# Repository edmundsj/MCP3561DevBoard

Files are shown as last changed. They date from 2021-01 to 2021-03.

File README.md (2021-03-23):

# MCP3561 Development Board
Development board for MCP3561 ADC, a <153kSpS
sigma-delta (oversampling) ADC capable of ~108dB SNR.

## Features
- 3.3V on-board reference
- low-noise 3.3V digital and analog supplies
- Powered via single 4V-12V input voltage
- Sampling rate tested up to 10kHz
- BNC input synchronization
- Single-channel SMA analog input
- Based on the Teensy 4.1, micro-USB communication to PC
- Additional digital/analog outputs (used here for motor control)

Populated PCB
Unpopulated PCB

## Performance Data
Measured with MCLK=10MHz, OSR=256, fs=9.76kHz, Av=1
- Rms voltage noise 9.8uV, PSD=143nV/rtHz, 0.2kHz to fs/2

Measured with MCLK=10MHz, OSR=256, fs=9.76kHz, Av=10
- Rms voltage noise is 13.4uV, PSD=195nV/rtHz, 0.2kHz to fs/2

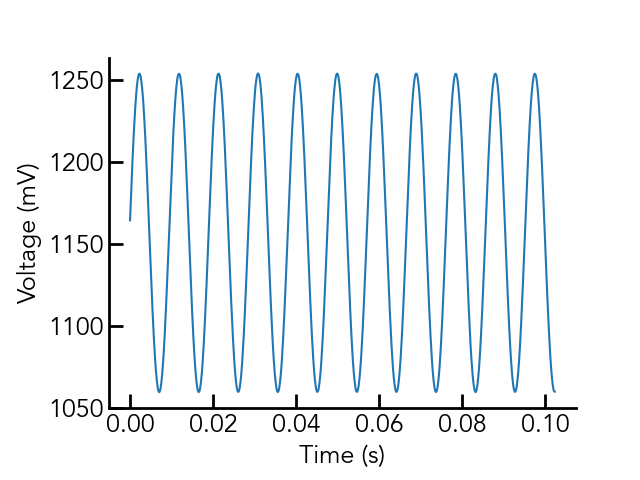
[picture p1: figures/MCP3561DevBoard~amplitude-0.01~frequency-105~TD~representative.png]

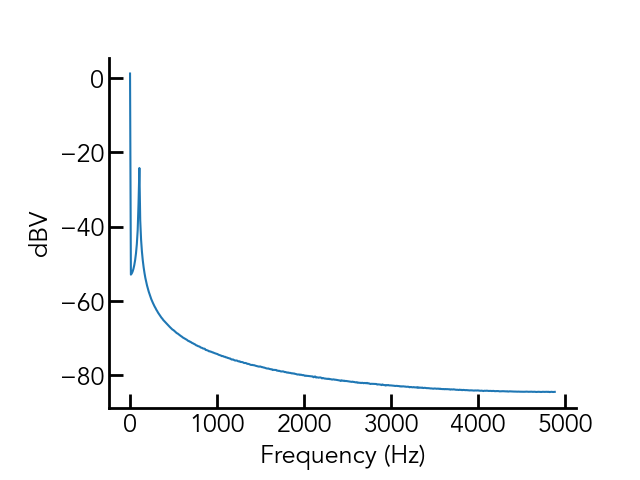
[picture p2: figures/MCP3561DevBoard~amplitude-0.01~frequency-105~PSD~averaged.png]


Fig. 3 and 4 show the same plots with an input signal of 10mVrms (Av=10) at
105Hz.

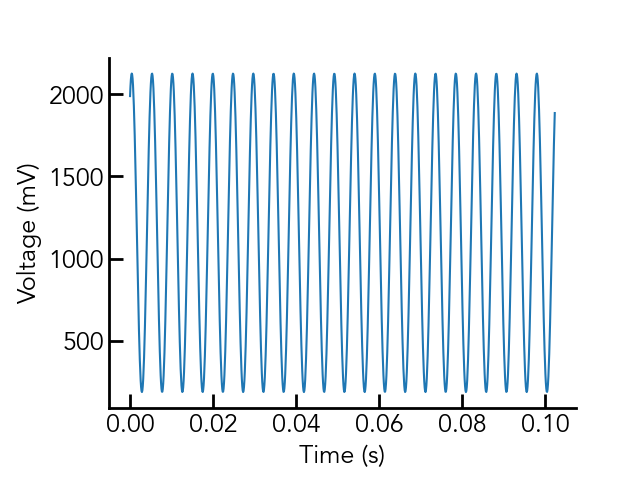
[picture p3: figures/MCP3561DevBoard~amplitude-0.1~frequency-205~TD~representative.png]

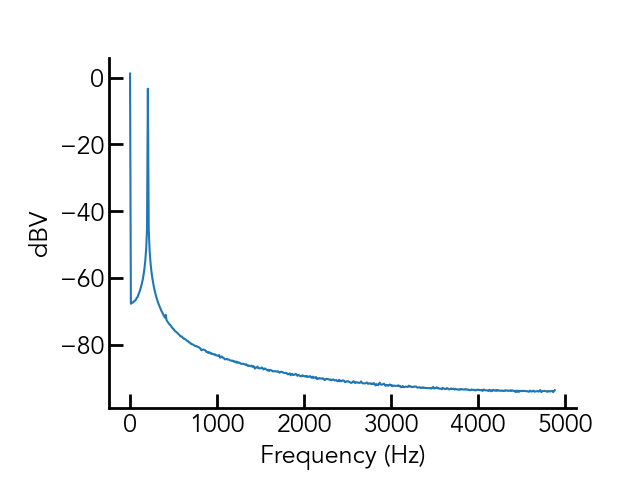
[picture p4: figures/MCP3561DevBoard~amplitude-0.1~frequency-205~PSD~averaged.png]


Fig. 5 and 6 show the same plots with an input signal of 100mVrms (Av=10) at
205Hz. 

## Getting Started
Using this dev board requires you have python installed on your computer, as
well as the Teensyduino IDE. You must then upload the code in ``arduino_code/``
to the Teensy being used for measurement, which I have written to communicate
via the arduino ``Serial()`` interface (USB) using the SCPI language. Feel free
to communicate with it using your own scripts, but I have written a python
implementation which can be found in ``MCP3561.py``
[here](https://github.com/edmundsj/AD7766_Python.git).

## Issues
### Issues in version 1
- [FIXED v2] U3 (TLV opamp) package is incorrect - TSOT353, actual package is SOT23-5.
- 1/f noise of TLV opamp is appreciable when configured for a gain of 10.

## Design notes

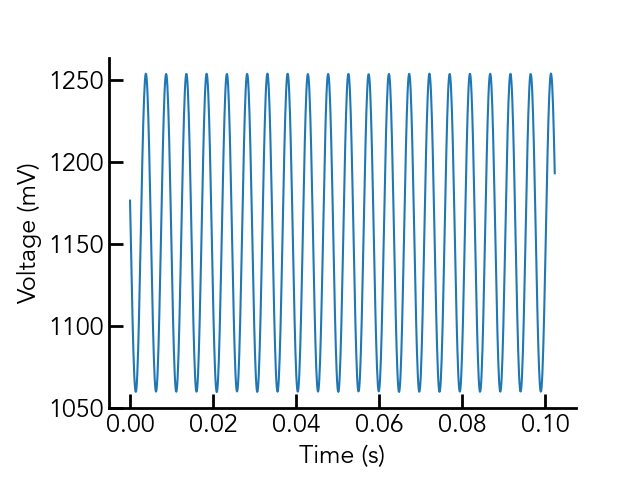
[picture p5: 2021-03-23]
figures/MCP3561DevBoard~amplitude-0.01~frequency-205~TD~representative.png

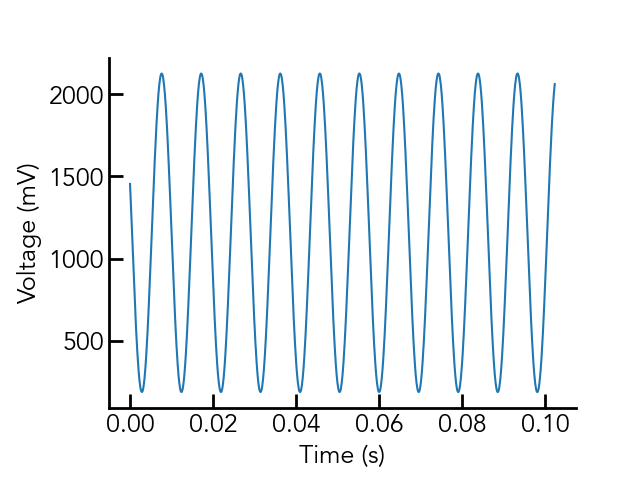
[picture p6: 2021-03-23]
figures/MCP3561DevBoard~amplitude-0.1~frequency-105~TD~representative.png

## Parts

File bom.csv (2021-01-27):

Part Name |  | Source | Catalog Number | Link | Quantity
U8 | Teensy4.1 | Digikey |  |  | 1
U7 | MCP3561 | Digikey | MCP3561RT-E/ST | https://www.digikey.com/en/products/detail/microchip-technology/MCP3561RT-E-ST/12807296 | 1
> U5, U6 | ADP3330-3.3 | Digikey | ADP3330ARTZ3.3-RL7CT-ND | https://www.digikey.com/en/products/detail/analog-devices-inc/ADP3330ARTZ3-3-RL7/1007321 | 2
U4 | ADR366 | Digikey | ADR366AUJZ-REEL7 | https://www.digikey.com/en/products/detail/analog-devices-inc/ADR366AUJZ-REEL7/996001 | 1
U3 | TLV9051 | Digikey | TLV9051IDBVR | https://www.digikey.com/en/products/detail/texas-instruments/TLV9051IDBVR/10715425 | 1
FL1-3 | LCL Filter | Digikey | 490-6957-1-ND | https://www.digikey.com/en/products/detail/murata-electronics/NFL21SP157X1C3D/2595155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 | 3
> R8-R12 | 10R | Digikey |  |  | 4
> R3, R6 | 1k | Digikey |  |  | 2
R7 | 100R | Digikey |  |  | 1
R5 | 3k | Digikey |  |  | 1
> R1, R4 | 10k | Digikey |  |  | 2
R2 | 320R | Digikey |  |  | 1
J8 | Screw_Terminal_01x02 | Digikey |  |  | 1
J5 | Conn_01x04 | Digikey |  |  | 1
J7 | Conn_01x10_Male | Digikey |  |  | 1
> J3, J4, J6 | Conn_02x03_Counter_Clockwise | Digikey |  |  | 3
J1 | Conn_Coaxial | Digikey |  |  | 1
J2 | Conn_Coaxial | Digikey |  |  | 1
> H1-H4 | MountingHole | Digikey |  |  | 4
> FL1, FL2 | EMI_Filter_LCL | Digikey |  |  | 2
D1 | DIODE | Digikey |  |  | 1
C7 | 100nF | Digikey |  |  | 1
> C1-C6, C8-C10 | 470nF | Digikey |  |  | 9

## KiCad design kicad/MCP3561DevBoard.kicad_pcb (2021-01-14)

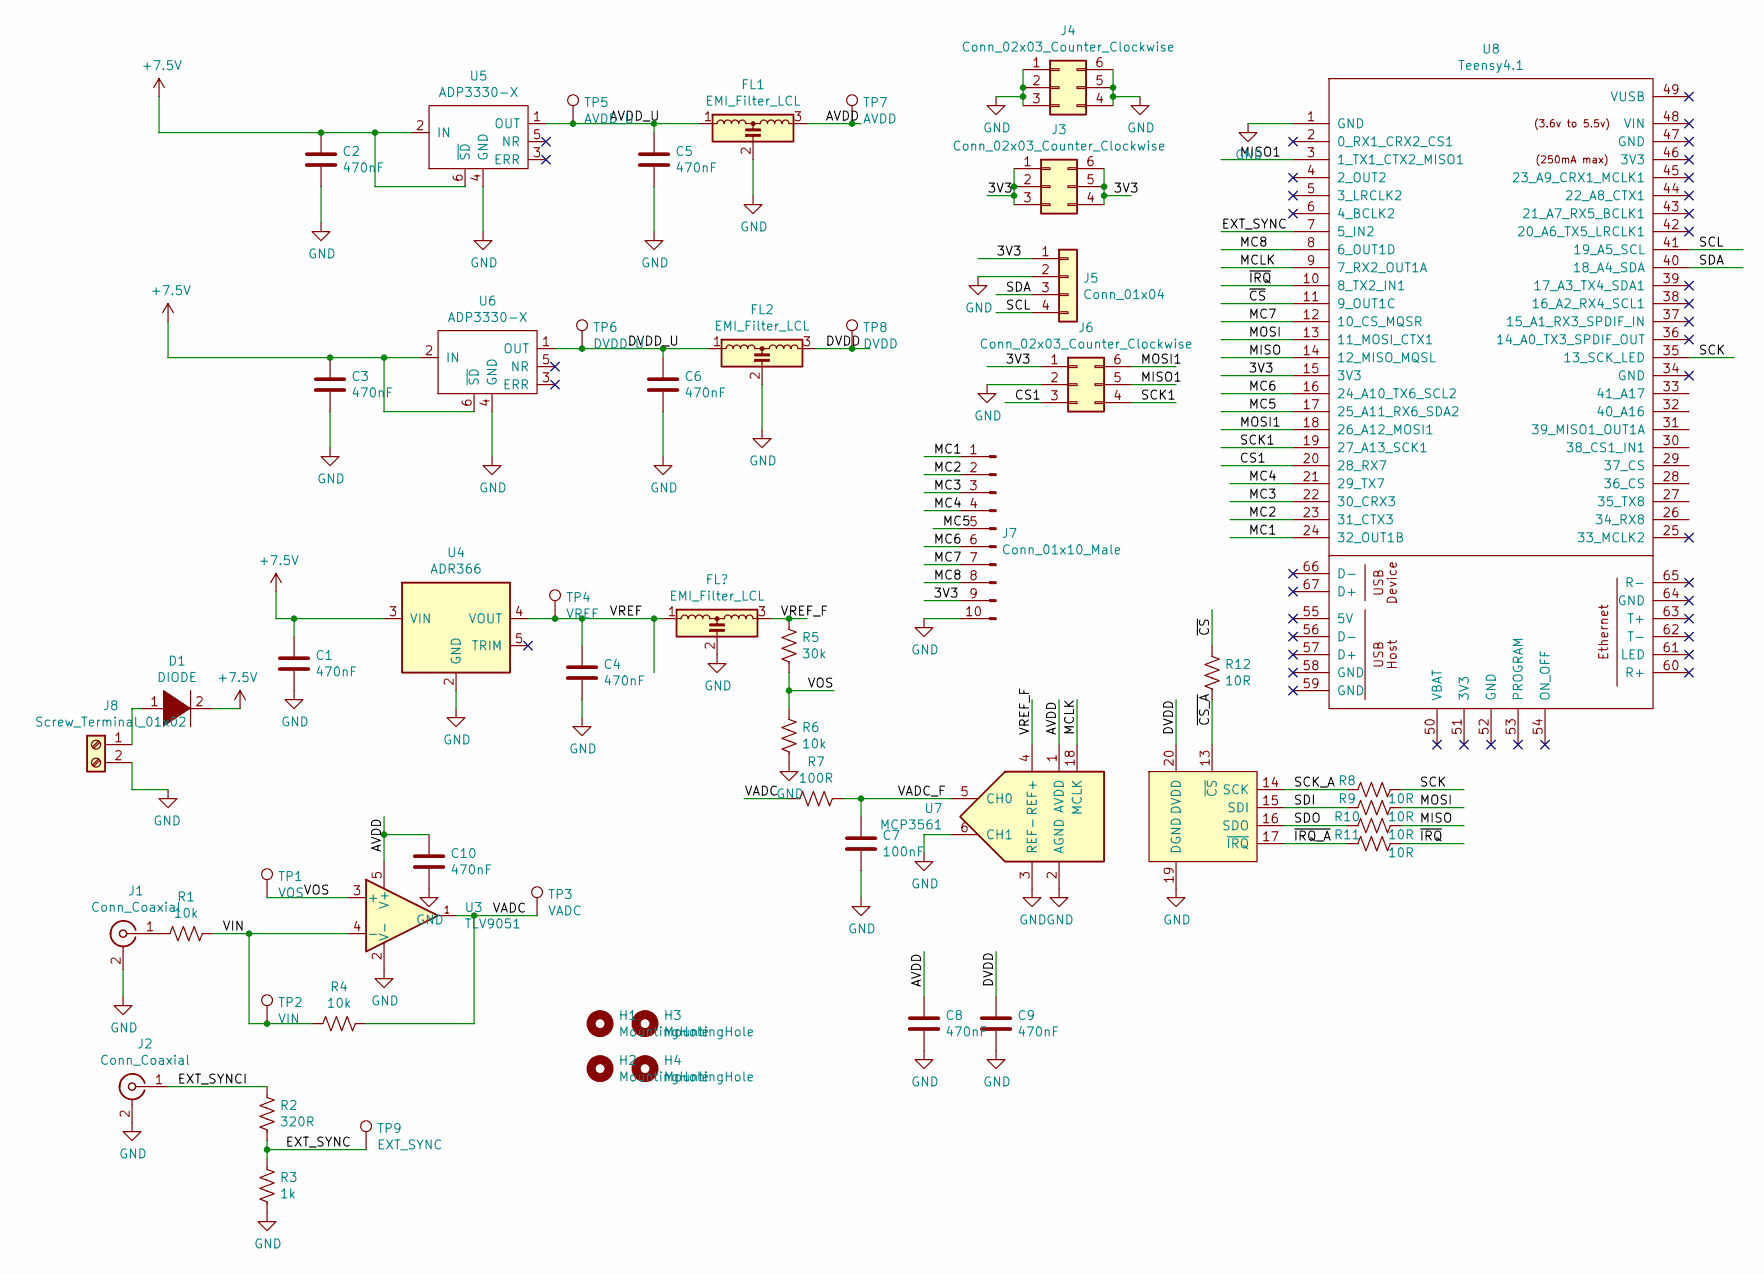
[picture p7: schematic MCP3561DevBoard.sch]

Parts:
C1, C2, C3, C4, C5, C6, C8, C9, C10: 470nF; C_0805_2012Metric_Pad1.15x1.40mm_HandSolder
C7: 100nF; C_0805_2012Metric_Pad1.15x1.40mm_HandSolder
D1: DIODE; D_SMA-SMB_Universal_Handsoldering
FL1, FL2: EMI_Filter_LCL; 0805_3TERM
H1, H2, H3, H4: MountingHole; m3_mounting_hole
J1: Conn_Coaxial; CON-SMA-EDGE-S
J2: Conn_Coaxial; BNC_JACK_RA
J3, J4, J6: Conn_02x03_Counter_Clockwise; PinHeader_2x03_P2.54mm_Vertical
J5: Conn_01x04; PinHeader_1x04_P2.54mm_Vertical
J7: Conn_01x10_Male; PinHeader_1x10_P2.54mm_Vertical
J8: Screw_Terminal_01x02; TerminalBlock_Altech_AK300-2_P5.00mm
R1, R4, R6: 10k; R_0805_2012Metric_Pad1.15x1.40mm_HandSolder
R2: 320R; R_0805_2012Metric_Pad1.15x1.40mm_HandSolder
R3: 1k; R_0805_2012Metric_Pad1.15x1.40mm_HandSolder
R5: 30k; R_0805_2012Metric_Pad1.15x1.40mm_HandSolder
R7: 100R; R_0805_2012Metric_Pad1.15x1.40mm_HandSolder
R8, R9, R10, R11, R12: 10R; R_0805_2012Metric_Pad1.15x1.40mm_HandSolder
TP1: VOS; TestPoint_Keystone_5000-5004_Miniature
TP2: VIN; TestPoint_Keystone_5000-5004_Miniature
TP3: VADC; TestPoint_Keystone_5000-5004_Miniature
TP4: VREF; TestPoint_Keystone_5000-5004_Miniature
TP5: AVDD_U; TestPoint_Keystone_5000-5004_Miniature
TP6: DVDD_U; TestPoint_Keystone_5000-5004_Miniature
TP7: AVDD; TestPoint_Keystone_5000-5004_Miniature
TP8: DVDD; TestPoint_Keystone_5000-5004_Miniature
TP9: EXT_SYNC; TestPoint_Keystone_5000-5004_Miniature
U3: TLV9051; SOT-23-5_HandSoldering
U4: ADR366; TSOT-23-5_HandSoldering
U5, U6: ADP3330-X; SOT-23-6_Handsoldering
U7: MCP3561; TSSOP-20_4.4x6.5mm_P0.65mm
U8: Teensy4.1; Teensy41

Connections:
+7.5V: C1.1, C2.1, C3.1, D1.2 (A), U4.3 (VIN), U5.2 (IN), U5.6 (~SD), U6.2 (IN), U6.6 (~SD)
/3V3: J3.1, J3.2, J3.3, J3.4, J3.5, J3.6, J5.1, J6.1, J7.9, U8.15 (3V3)
/AVDD: C8.1, C10.1, FL1.3, TP7.1, U3.5 (V+), U7.1 (AVDD)
/AVDD_U: C5.1, FL1.1, TP5.1, U5.1 (OUT)
/CS1: J6.3, U8.20 (28_RX7)
/DVDD: C9.1, FL2.3, TP8.1, U7.20 (DVDD)
/DVDD_U: C6.1, FL2.1, TP6.1, U6.1 (OUT)
/EXT_SYNC: R2.2, R3.1, TP9.1, U8.7 (5_IN2)
/EXT_SYNCI: J2.1 (In), R2.1
/MC1: J7.1, U8.24 (32_OUT1B)
/MC2: J7.2, U8.23 (31_CTX3)
/MC3: J7.3, U8.22 (30_CRX3)
/MC4: J7.4, U8.21 (29_TX7)
/MC5: J7.5, U8.17 (25_A11_RX6_SDA2)
/MC6: J7.6, U8.16 (24_A10_TX6_SCL2)
/MC7: J7.7, U8.12 (10_CS_MQSR)
/MC8: J7.8, U8.8 (6_OUT1D)
/MCLK: U7.18 (MCLK), U8.9 (7_RX2_OUT1A)
/MISO: R10.1, U8.14 (12_MISO_MQSL)
/MISO1: J6.5, U8.3 (1_TX1_CTX2_MISO1)
/MOSI: R9.1, U8.13 (11_MOSI_CTX1)
/MOSI1: J6.6, U8.18 (26_A12_MOSI1)
/SCK: R8.1, U8.35 (13_SCK_LED)
/SCK1: J6.4, U8.19 (27_A13_SCK1)
/SCK_A: R8.2, U7.14 (SCK)
/SCL: J5.4, U8.41 (19_A5_SCL)
/SDA: J5.3, U8.40 (18_A4_SDA)
/SDI: R9.2, U7.15 (SDI)
/SDO: R10.2, U7.16 (SDO)
/VADC: R4.1, R7.2, TP3.1, U3.1 (OUT)
/VADC_F: C7.1, R7.1, U7.5 (CH0)
/VIN: R1.1, R4.2, TP2.1, U3.4 (-)
/VOS: R5.2, R6.1, TP1.1, U3.3 (+)
/~CS: R12.1, U8.11 (9_OUT1C)
/~CS_A: R12.2, U7.13 (~CS)
/~IRQ: R11.1, U8.10 (8_TX2_IN1)
/~IRQ_A: R11.2, U7.17 (~IRQ)
GND: C1.2, C2.2, C3.2, C4.2, C5.2, C6.2, C7.2, C8.2, C9.2, C10.2, FL1.2, FL2.2, J1.2 (Ext), J2.2 (Ext), J4.1, J4.2, J4.3, J4.4, J4.5, J4.6, J5.2, J6.2, J7.10, J8.2, R3.2, R6.2, U3.2 (V-), U4.2 (GND), U5.4 (GND), U6.4 (GND), U7.2 (AGND), U7.3 (REF-), U7.6 (CH1), U7.19 (DGND), U8.1 (GND)
unnamed: D1.1 (K), J8.1
unnamed: J1.1 (In), R1.2

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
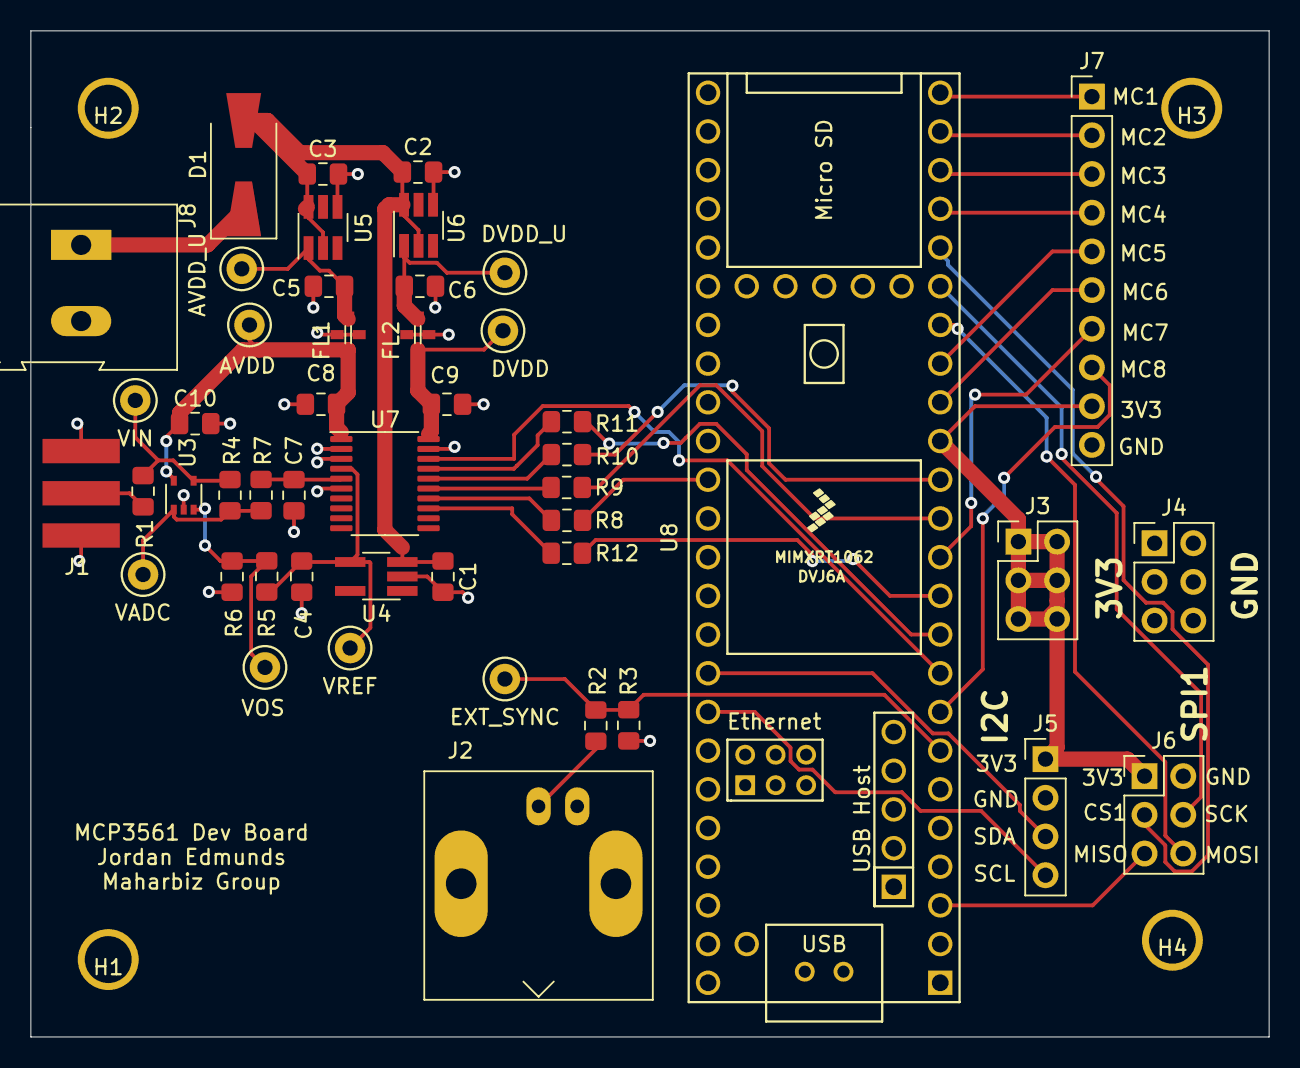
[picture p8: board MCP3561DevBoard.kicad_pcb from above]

Board: 2 copper layers, 81.3 x 66.0 mm, 52 parts (0 on the bottom side), 41 nets.

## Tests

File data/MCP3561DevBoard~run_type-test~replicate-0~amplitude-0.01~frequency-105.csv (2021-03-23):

{'sampling_frequency': 9760 | 'n_samples': 1000}
Time (s) | Voltage (mV) | Sync
0.0 | 1107.8404068946838 | 0
0.00010245901639344262 | 1113.5225415229797 | 0
0.00020491803278688525 | 1119.4418907165527 | 0
0.00030737704918032784 | 1125.5854725837705 | 0
0.0004098360655737705 | 1131.8742156028748 | 0
0.0005122950819672131 | 1138.2235407829285 | 0
0.0006147540983606557 | 1144.8533535003662 | 0
0.0007172131147540983 | 1151.3808846473694 | 0
0.000819672131147541 | 1157.996141910553 | 0
0.0009221311475409836 | 1164.589762687683 | 0
0.0010245901639344263 | 1171.0386157035828 | 0
0.001127049180327869 | 1177.5035977363586 | 0
0.0012295081967213114 | 1183.8411211967468 | 0
0.001331967213114754 | 1190.020501613617 | 0
0.0014344262295081967 | 1196.0854053497314 | 0
0.0015368852459016393 | 1201.9579410552979 | 0
0.001639344262295082 | 1207.6743006706236 | 0
0.0017418032786885246 | 1213.28444480896 | 0
0.0018442622950819673 | 1218.5771226882932 | 0
0.00194672131147541 | 1223.3670473098755 | 0
0.0020491803278688526 | 1227.956736087799 | 0
0.002151639344262295 | 1232.254135608673 | 0
0.002254098360655738 | 1236.1907958984375 | 0
0.0023565573770491805 | 1239.8017287254333 | 0
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

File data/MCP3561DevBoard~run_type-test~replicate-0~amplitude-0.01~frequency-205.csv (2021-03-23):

{'sampling_frequency': 9760 | 'n_samples': 1000}
Time (s) | Voltage (mV) | Sync
0.0 | 1123.9529013633726 | 0
0.00010245901639344262 | 1112.1901273727417 | 0
0.00020491803278688525 | 1101.2188553810117 | 0
0.00030737704918032784 | 1091.4021849632263 | 0
0.0004098360655737705 | 1082.601249217987 | 0
0.0005122950819672131 | 1074.899446964264 | 0
0.0006147540983606557 | 1068.736982345581 | 0
0.0007172131147540983 | 1064.1307711601257 | 0
0.000819672131147541 | 1061.09379529953 | 0
0.0009221311475409836 | 1059.781837463379 | 0
0.0010245901639344263 | 1060.2385640144348 | 0
0.001127049180327869 | 1062.2641324996948 | 0
0.0012295081967213114 | 1065.8475279808044 | 0
0.001331967213114754 | 1071.0434317588806 | 0
0.0014344262295081967 | 1077.7790665626526 | 0
0.0015368852459016393 | 1085.833740234375 | 0
0.001639344262295082 | 1095.0949430465698 | 0
0.0017418032786885246 | 1105.3769946098325 | 0
0.0018442622950819673 | 1116.7581796646118 | 0
0.00194672131147541 | 1128.8171768188474 | 0
0.0020491803278688526 | 1141.1539077758787 | 0
0.002151639344262295 | 1153.9060592651367 | 0
0.002254098360655738 | 1166.6944026947021 | 0
0.0023565573770491805 | 1179.3222427368164 | 0
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

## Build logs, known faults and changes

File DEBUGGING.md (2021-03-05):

Appendix - Notes
-------------------
- I will try to solder on U3 anyway despite its smaller package. I have a microscope, hopefully that will help :p.
- Got it. Damn that was not trivial, don't know how I would have done it without a microscope.
- All input voltages are as expected, 3.3V except for VOS, which is 0.8V (3.3V/4). With the labeled test points it was SO EASY to do this test. It took a total of like 5 seconds. Now we solder on the teensy and attempt to write software to communicate with the ADC.
- Soldering the ADC on applying flux liberally and a very small amount of solder to the tip was pretty trivial.
- Why is the ADC data 32 bits and not 24? Is it sending a checksum or something? Nope, the checksum is 16 bits. Nope, default length is 24 bits.
- Does this chip have no static write? God that's going to be annoying to deal with.
- I was seeing strange periodic pulses on the Teeny's supply - turns out the thing was not actually connected to ground! I left the pin floating because I didn't have a long-enough header and didn't realize that was where my ground pin was connected.
- We are sending a clock signal on the SPI SCK line, but we are not getting any data back from the ADC. We should verify that the registers we wrote have the correct values.
- The ADC is completely silent when I try to read its registers. They all contain nothing. I suspect the ADC is locked or I am not sending the right command.
- Much better. I forgot to send the address on the SPI bus. Stupid protocol. 
- I have verified that the CONFIG0-3 registers have the correct value. MCLK is going off at 4.69MHz, and pin 7 of the Teensy is being driven. The ADC data is in continuous conversion mode, but all the bits we are getting back are zero.
- When I plugged in the ADC initially today it was reading all zeros - this tells me that I am trying to write the register defaults too fast. I added a 100ms delay on startup prior to writing to try to fix this. This doesn't seem to work. 500ms does seem to work.
- For some reason our beginReadingData() function isn't working, we simply re-read the last ADC value over and over again.
- Our readRegisters() command works, but beginReadingData() does not. What's the difference? We are doing an incremental read in the one case and a static read in the other. Not sure why this would make a difference.
- So the static read is working, but the continuous read is not. It seems like the ADC is not continually generating new data (or updating the output register) until we send the read command. This is fine for now. This is fine for now.
- The master clock of the ADC is running at 4.691MHz, and the data appears to be ready at a frequency of 4.584kHz, which would seem to indicate there is one sample every 1024 clock cycles. According to the datasheet at this clock frequency and an oversampling ratio of 256, the data rate should be 4.581kHz, which is very close to what we see. This means the ADC is working as expected. The interrupt pin is also working well, so we need to implement that.
- Everything is now working, sampling at 4.8kHz. 
- Looks like I can sample at 36.8kHz, but the data is in steps of 180, not steps of 1 anymore. That's obnoxious. For now I'll just stick with a sampling rate of 4.8kHz and characterize the ADC, then switch to a higher sampling rate.
- For now, I have commented out all the motor and synchronization code, but even the identify code is not working. Ported code is now working.
- I will test using a 10MHz clock at the input

Unit Test Debugging
____________________
- I am having some issues getting 300,000 bytes back from the arduino. I suspect this is a time-out error, as we need to wait quite a long time to get back this data. I'm receiving around 40kB, which indicates we only take ~10 measurements. I'm going to try to do this manually.
- The teensy itself can send 100k samples no problem.
- Sure enough, our Measure() method is terminating too early. Fixed it, now it's working up to 100k measurements.
- All motor communication unit tests are now passing, as are all measurement tests. Still failing synchronization tests, which means I will have to solder on the connector. Time to do that.
- Today the measurement frequency is 4.58kHz. This is significantly lower than yesterday, it looks like the internal clock drifts quite a bit. Let's drive the clock using the Teensy to try to get a more reliable sampling rate.
- Synchronization is not currently working. I'm going to let that issue rest for now. The discrepancy is small. 
- When applying an input sinusoid wih a shielded cable, it looks like the noise goes up to high heaven. This looks like it is low-frequency noise from the signal generator itself, as there is no noise present when I turn the output of the signal generator off. Fortunately this shouldn't matter for us, as the signal generator is only used to apply voltages to my devices, but this is very good to know.

Debugging TIA
________________
- After testing the ADC, with the ADC + TIA, the noise goes up to 13uVrms / 190nV/rtHz, which is *exactly* what I would expect of a 1MOhm resistor. There is now a -110dBV 60Hz signal present in the spectra which was not there before. This indicates that my current TIA is coupling this noise, likely via the cables, into the input of the ADC. But DAMN the noise is close to what I would expect. The single-ended-to-differential discrete PCB appears to have been the main noise culprit.
- I can now relegate my old ADC, the AD7766, to the ashheap of history. I still need to properly wire the motor controller, but that frees up my old teensy as well. The -110dBV harmonic is now up to -105dBV.
- With the photodiode attached, the 60Hz harmonic goes up to -93dBV, and the 120Hz harmonic goes up to -90dBV. This goe up dramatically when I remove the Faraday cage, though I suspect this has to do with light.
- When I mount the new Si photodiode, the noise is just as bad. This tells me it's not a shielding problem, but an ambient light problem. When i cover the device with my hand, it goes away.
- After putting the photodiode in a cardboard box, the noise went down to ~-80dBV, and after wrapping that mostly in aluminum foil, the noise went down to -106dBV, indicating we are now limited by the TIA. If we want to get down to below -110dBV, we need to fabricate a new TIA. This means we can do shot-noise limited measurements at 60Hz above 70uA. But with a TIA redesign, we can bring that interferer down below the TIA noise floor, and do shot-noise limited measurements down to 70nA. With the losses in the system, this is probably going to be necessary. I should send out a new TIA design with the new Teensy and thermal management PCB designs.

Debugging Motor
__________________
- It looks like the Teensy thinks the motor is enabled, but the motor is not getting any current.
- For some reason the teensy is not consistently writing to the enable/disable pin when I tell it to. When the device is reset, it does not, but when the enable/disable function is called directly, it does. This means there is something in the reset code that is setting the motor back to an enabled state. Indeed, that was the case.
- Now, it looks like my waitForMotor() function is not working at all - my test code is not waiting long enough fro my motor to rotate. I suspect the teensy does not respond fast enough and when the python code queries it, the motor has not set the rotating bit to true yet. We may need to add a tiny delay up-front to fix this.
- Nope this appears not to be the issue. The code appears to run just fine when I run it in a python shell. Here is my guess: the time.sleep function does not work in the unittest module. Nope, this is not the case either. Ah, I think the motor is not on. Yup, adding an internal check for whether the motor is on fixed this.
- When rotating the motor there is a -115dBV interferer at 500Hz and a -118dBV harmonic at 1kHz, -122dBV at 1.5kHz. I suspect this is due to the motor. This means we probably don't care if the motor is enabled. but we do care if it's actually rotating.
- OK, now we have got the motor completely working once again.
- Today there is a -100dBV interferer at 60Hz coupling in from the TIA and a -110dBV interferer at 180Hz. When I turn on the Tekpower DC supply which connects to the motor there is also a -97dBV interferer at 4kHz, which is not present when the motor is disabled. So today we just have slightly worse 60Hz noise on the TIA. Not unexpected. With the photodiode plugged in, this stays about the same but there is also now a -120dBV interferer at 120Hz, which is indicative that I need a better aluminum foil box. With extra tinfoil, the interferer dissapeared, indicating it was in fact due to overhead lighting.

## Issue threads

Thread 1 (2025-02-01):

Trying to use mcp3561.h

KrisKasprzak, 2025-02-01:
Edmundsj,

I'm trying to use an MCP3654 ADC chip (the 8 channel version of the MCP3561). I've yet to find a public lib and the what the datasheet was written regarding programming is not something I understand. My MCU is a Teensy 3.2 and using Arduino IDE. I tool your mcp3561.h and created a simple sketch, but the printRegisters() displays all 0's. One time i did get some values, but never again.

I'm really hoping you can help me out. Maybe we can start here?

1. what pin connections do you use? I do have 2 x 0.1 uf decoupling cap and IRQ to 3v3 Ref- to GND, and Ref+ to 3V3
2.  I see your SPI calls do not have a beginTransaction() / endTransaction(). I added them but that did not help
3.  I DEVICE_ADDRESS from 0b00, 0b01,0b10, 0b11 but that did not help

I know I'm asking a lot, but I'm really stuck.

Output of my code to the serial monitor is:
////////////////////////////////////////////////////////////////////////////////////

Starting..........................................................................................
DEVICE_ADDRESS 0     // note I have tried 0b00, 0b01,0b10, 0b11
writeRegisterDefaults...
registers read...
SOME REGISTER NOT OK. REGISTER TABLE:
CONFIG0: BAD
CONFIG1: BAD
CONFIG2: BAD
CONFIG3: BAD
IRQ: BAD
registers verifyRegisters...
ADCDATA Register: 000
CONFIG0: 0
CONFIG1: 0
CONFIG2: 0
CONFIG3: 0
IRQ: 0
MUX: 0
SCAN: 0
TIMER: 0
OFFSETCAL: 0
GAINCAL: 0
RESERVED1: 0
RESERVED2: 0
LOCK: 0
RESERVED3: 0
CRCCFG: 0
-----------------------------
registers should have been printed...
kris.data_counter 0
kris.data_points_to_sample 1
Data Read Interrupt Activated. data_counter: 0/1
reading adc:
ADC raw data: 0
do we have some data?...

Heres my code
////////////////////////////////////////////////////////////////////////////////////

#include "MCP3564.h"
#include "SPI.h"

MCP3561 kris;

void setup() {

  Serial.begin(115200);
  Serial.println();
  Serial.println("Starting..........................................................................................");

  SPI.begin();

  Serial.print("DEVICE_ADDRESS ");
  Serial.print(DEVICE_ADDRESS);
  Serial.println("     // note I have tried 0b00, 0b01,0b10, 0b11");
  kris.writeRegisterDefaults();
  Serial.println("writeRegisterDefaults...");

  kris.readRegisters();
  Serial.println("registers read...");

  kris.verifyRegisters();
  Serial.println("registers verifyRegisters...");

  kris.printRegisters();
  Serial.println("registers should have been printed...");

  Serial.print("kris.data_counter ");
  Serial.println(kris.data_counter);

  Serial.print("kris.data_points_to_sample ");
  Serial.println(kris.data_points_to_sample);

  kris.readADCData();
  Serial.print("ADC raw data: ");
  Serial.println(kris.adc_sample);
  Serial.println("do we have some data?...");
}

void loop() {
 // kris.readADCData();
 // Serial.println(kris.adc_sample);
 // delay(1000);
}

KrisKasprzak, 2025-02-01:
Here's what's odd 2 tries

I just Plugged my chip in and I get some data--not sure if its correct or not

Starting..........................................................................................
DEVICE_ADDRESS 1     // note I have tried 0b00, 0b01,0b10, 0b11
writeRegisterDefaults...
registers read...
SOME REGISTER NOT OK. REGISTER TABLE:
CONFIG0: BAD
CONFIG1: OK
CONFIG2: OK
CONFIG3: BAD
IRQ: BAD
registers verifyRegisters...
ADCDATA Register: 000
CONFIG0: 11000000
CONFIG1: 1100
CONFIG2: 10001011
CONFIG3: 0
IRQ: 1100011
MUX: 1
SCAN: 0
TIMER: 0
OFFSETCAL: 0
GAINCAL: 0
RESERVED1: 0
RESERVED2: 0
LOCK: 0
RESERVED3: 0
CRCCFG: 0
-----------------------------
registers should have been printed...
kris.data_counter 0
kris.data_points_to_sample 1
Data Read Interrupt Activated. data_counter: 0/1
reading adc:
ADC raw data: 12582912
do we have some data?...

UNplugging and plugging back in....

Starting..........................................................................................
DEVICE_ADDRESS 1     // note I have tried 0b00, 0b01,0b10, 0b11
writeRegisterDefaults...
registers read...
SOME REGISTER NOT OK. REGISTER TABLE:
CONFIG0: BAD
CONFIG1: BAD
CONFIG2: BAD
CONFIG3: BAD
IRQ: BAD
registers verifyRegisters...
ADCDATA Register: 000
CONFIG0: 0
CONFIG1: 0
CONFIG2: 0
CONFIG3: 0
IRQ: 0
MUX: 0
SCAN: 0
TIMER: 0
OFFSETCAL: 0
GAINCAL: 0
RESERVED1: 0
RESERVED2: 0
LOCK: 0
RESERVED3: 0
CRCCFG: 0
-----------------------------
registers should have been printed...
kris.data_counter 0
kris.data_points_to_sample 1
Data Read Interrupt Activated. data_counter: 0/1
reading adc:
ADC raw data: 0
do we have some data?...

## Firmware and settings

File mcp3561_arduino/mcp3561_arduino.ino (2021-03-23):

#include <SPI.h>
#include "teensyDAQ.h"

struct scpi_parser_context ctx;
char line_buffer[256];
unsigned char read_length;

void setup() {
  scpi_init(&ctx);
  struct scpi_command* motor;
  struct scpi_command* sync;

  scpi_register_command2(ctx.command_tree, SCPI_CL_SAMELEVEL, "*IDN?", identify);
  scpi_register_command2(ctx.command_tree, SCPI_CL_SAMELEVEL, "MEASURE?", measure);
  scpi_register_command2(ctx.command_tree, SCPI_CL_SAMELEVEL, "CONFIGURE", configure);
  scpi_register_command2(ctx.command_tree, SCPI_CL_SAMELEVEL, "CONFIGURE?", queryConfiguration);
  scpi_register_command2(ctx.command_tree, SCPI_CL_SAMELEVEL, "*RST", resetDevice);
  
  sync = scpi_register_command2(ctx.command_tree, SCPI_CL_SAMELEVEL, "SYNC", NULL);
  scpi_register_command2(sync, SCPI_CL_CHILD, "NUMPOINTS?", sendSyncNumPoints);
  scpi_register_command2(sync, SCPI_CL_CHILD, "DATA?", sendSyncData);

  motor = scpi_register_command2(ctx.command_tree, SCPI_CL_SAMELEVEL, "MOTOR", NULL);
  scpi_register_command2(motor, SCPI_CL_CHILD, "POSITION", setPosition);
  scpi_register_command2(motor, SCPI_CL_CHILD, "POSITION?", queryPosition);
  scpi_register_command2(motor, SCPI_CL_CHILD, "DIRECTION?", queryDirection);
  scpi_register_command2(motor, SCPI_CL_CHILD, "ROTATE", rotateMotor);
  scpi_register_command2(motor, SCPI_CL_CHILD, "ROTATE?", getMotorRotating);
  scpi_register_command2(motor, SCPI_CL_CHILD, "ENABLE", enableMotor);
  scpi_register_command2(motor, SCPI_CL_CHILD, "DISABLE", disableMotor);
  scpi_register_command2(motor, SCPI_CL_CHILD, "ENABLED?", getMotorEnabled);
  scpi_register_command2(motor, SCPI_CL_CHILD, "PERIOD", setMotorPeriod);
  scpi_register_command2(motor, SCPI_CL_CHILD, "PERIOD?", getMotorPeriod);
  
  // put your setup code here, to run once:
  Serial.begin(9600);
  pinMode(CS_PIN, OUTPUT);
  pinMode(IRQ_PIN, INPUT);
  pinMode(MCLK_PIN, OUTPUT);
  pinMode(MISO_PIN, INPUT);
  analogWriteFrequency(MCLK_PIN, 10240000);
  analogWrite(MCLK_PIN, 128);
  SPI.begin();
  
  delay(500); // I think we need an initial delay.
  adc.writeRegisterDefaults();

  adc.readRegisters();
  //adc.verifyRegisters();
}

void loop() {
  if(Serial.available()) {
    read_length = Serial.readBytesUntil('\n', line_buffer, 256);
    if(read_length > 0)
    {
      scpi_execute_command(&ctx, line_buffer, read_length);
    }
  }
}

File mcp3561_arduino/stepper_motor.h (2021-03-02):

#include <Arduino.h>
#define MC1 32
#define MC2 31
#define MC3 30
#define MC4 29
#define MC5 25
#define MC6 24
#define MC7 10
#define MC8 6


class StepperMotor {
  public:
    StepperMotor();
    void beginRotation(int);
    void setDirection(int);
    void Rotate(void);
    void Enable(void);
    void Disable(void);
    void Reset(void);
    void setMotorSpeed(int);

    uint32_t motorPeriod;
    bool motorEnabled;
    int stepsRemaining; // this should be an int to avoid underflow errors.
    bool motorRotating;
    int motorPosition;
    int motorDirection;
  private:
    const int directionPin = MC1;
    const int stepPin = MC2;
    const int sleepPin = MC3;
    const int resetPin = MC4;
    const int ms3Pin = MC5;
    const int ms2Pin = MC6;
    const int ms1Pin = MC7;
    const int enablePin = MC8;
};

StepperMotor::StepperMotor(void) {
  
  pinMode(this->directionPin, OUTPUT); 
  pinMode(this->stepPin, OUTPUT);
  pinMode(this->sleepPin, OUTPUT);
  pinMode(this->resetPin, OUTPUT);
  pinMode(this->ms3Pin, OUTPUT);
  pinMode(this->ms2Pin, OUTPUT);
  pinMode(this->ms1Pin, OUTPUT);
  pinMode(this->enablePin, OUTPUT);
  this->Reset();
 
}

void StepperMotor::beginRotation(int numberSteps) {
  this->motorRotating = true;
  
  if(numberSteps < 0) {
    this->setDirection(1);
    numberSteps *= -1;
  }
  else {
    this->setDirection(0);
  }
  this->stepsRemaining = numberSteps;
  
}

void StepperMotor::Rotate(void) {
  this->stepsRemaining -= 1;
  if(this->motorDirection == 0) {
    this->motorPosition += 1;
  }
  else {
    this->motorPosition -= 1;
  }
  digitalWrite(this->stepPin, LOW);
  digitalWrite(this->stepPin, HIGH);
}

void StepperMotor::setDirection(int newDirection) {
  this->motorDirection = newDirection;
  if(newDirection == 0) digitalWrite(this->directionPin, LOW);
  else if (newDirection == 1) digitalWrite(this->directionPin, HIGH);
  else this->motorDirection = 0;
}

void StepperMotor::Disable() {
  digitalWrite(this->enablePin, HIGH);
  this->motorEnabled = 0;
}

void StepperMotor::Enable() {
  digitalWrite(this->enablePin, LOW);
  this->motorEnabled = 1;
}

void StepperMotor::Reset() {
  this->motorPosition = 0;
  this->motorDirection = 0;
  this->motorPeriod = 2;
  this->motorEnabled = 1;
  this->stepsRemaining = 0;
  this->motorRotating = false;
  this->Disable();
  
  digitalWrite(this->ms3Pin, HIGH); // use the finest possible (1/16 step) microstepping
  digitalWrite(this->ms2Pin, HIGH);
  digitalWrite(this->ms1Pin, HIGH);

  digitalWrite(this->directionPin, this->motorDirection);
  digitalWrite(this->stepPin, HIGH);

  digitalWrite(this->sleepPin, HIGH); // sleep is active low
  digitalWrite(this->resetPin, HIGH); // reset is active low
  digitalWrite(this->resetPin, LOW); // reset the controller
  digitalWrite(this->resetPin, HIGH); // go back to an on state
}

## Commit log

2021-01-14 first version of MCP3561 development board, contains socket for teensy, test points, power via screw terminals, a voltage reference, a unity-gain preamplifier
    [MCP35461DevBoard-B_Cu.gbr, MCP35461DevBoard-B_Mask.gbr, MCP35461DevBoard-B_Paste.gbr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]
2021-01-14 fixed power plane so that it contains voltage reference
    [MCP35461DevBoard-B_Cu.gbr, MCP35461DevBoard-B_Mask.gbr, MCP35461DevBoard-B_Paste.gbr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]
2021-01-14 added bill of materials with full component list and partial cart
    [bom.csv]
2021-01-19 updated schematic and backup
    [MCP3561DevBoard.sch]
2021-01-27 added basic arduino code for SCPI communication over serial with arduino. Tested and works at 4.8kHz, there is some funky stuff going on at 38kHz, the ADC has a lower resolution and I'm not sure how 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
    [MCP3561DevBoard.sch, bom.csv]
2021-01-28 added stepper motor, fixed code on MCP so that all unit tests are passing
    [mcp3561.h, mcp3561_arduino.ino, stepper_motor.h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]
2021-03-02 switched README.rst to README.md for better github compatibility. Added updates to teensy code, and added a figure for adc noise
    [MCP3561_grounded_input.csv, test_data_raw.csv]
2021-03-05 removed old figures, data. Added figures to README
    [MCP3561_grounded_input.csv, test_data_raw.csv]
2021-03-05 added raw data and figures for grounded input, 10mVrms input, and 100mVrms input
    [MCP3561DevBoard_100mVrms_replicate-0.csv, MCP3561DevBoard_100mVrms_replicate-1.csv, MCP3561DevBoard_100mVrms_replicate-10.csv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]
2021-03-05 added personal notes from debugging the PCB
2021-03-08 updated README, added additional figures, PCB photos
    [MCP3561DevBoard.kicad_pcb, MCP3561DevBoard.sch]
2021-03-12 added new data, figures for MCP dev board, varying frequency and voltage
    [MCP3561DevBoard~replicate-0~amplitude-0.01~frequency-105.csv, MCP3561DevBoard~replicate-0~amplitude-0.01~frequency-205.csv, MCP3561DevBoard~replicate-0~amplitu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]
2021-03-23 added updated data, plots
    [MCP3561DevBoard~replicate-0~amplitude-0.01~frequency-105.csv, MCP3561DevBoard~replicate-0~amplitude-0.01~frequency-205.csv, MCP3561DevBoard~replicate-0~amplitu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]
